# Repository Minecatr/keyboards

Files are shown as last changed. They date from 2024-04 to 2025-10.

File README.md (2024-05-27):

# Compiling firmware with QMK MSYS
- Install [QMK MSYS](https://msys.qmk.fm/)
- Setup QMK MSYS
- Clone this project into `qmk_firmware/keyboards/minecatr` *this means this repositories contents go in here
- Copy the build folder of the desired keyboard into the QMK MSYS directory
- Run `qmk compile -e CONVERT_TO=promicro_rp2040 -kb {PATH TO KEYBOARD} -km default` in QMK MSYS
- Output should be in `qmk_firmware/.build`
## Using other bootloaders
If your MCU does not use UF2 it likely supports one of these other bootloaders
### Caterina
`qmk flash -kb /build -km default`

### [Other Bootloaders](https://github.com/qmk/qmk_firmware/blob/master/docs/flashing.md)
# Using VIA to change layout
- Install [VIA](https://github.com/the-via/releases/releases) or use the [web version](https://www.usevia.app/)
- Navigate to settings and enable show design tab
- Navigate to design and press load
- Select the the via.json file of the desired board

a preconfigured layout.json is in each complete board

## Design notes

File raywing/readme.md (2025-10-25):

# RAYWING



a split choc keyboard with 54 backlit keys 2 rotary encoders and a flippable board
## Parts
- RGB LEDs: SK6812 MINI-E 100pcs https://www.aliexpress.us/item/2255800289371100.html
- MCU: Any Arduino Pro Micro Form Board
- EVQWGD001 Encoder: https://www.aliexpress.us/item/3256806010310254.html
- Diodes: DO-35 1N4148 100pcs https://www.aliexpress.us/item/3256805608834808.html
- Hotswap: Mill-Max Sockets (any) https://ringerkeys.com/collections/modders-tools/products/mill-max-hot-swap-sockets?variant=32793029312594](https://mech.land/products/mill-max-sockets?variant=39832065081497
- Switches: Any Choc V1 Compatible https://chosfox.com/collections/kailh-low-profile-switch-pg1350/products/kailh-chocs
- Keycaps: Any Choc V1 Compatible
- TRRS: PJ-320A https://www.aliexpress.us/item/2251832843150354.html
- TRRS Cable: Any 4 Ring TRRS Cable
  - If you have a 3 ring cut off the last pin on the TRRS socket
## Ordering A PCB
1. Download Gerbers Located `/kicad/production/Raywing.zip`
2. Choose Preferred PCB service
  - JLCPCB: https://cart.jlcpcb.com/quote
  - PCBWAY: https://www.pcbway.com/
  - DIGIKEY: https://www.digikey.com/en/resources/design-tools/pcb-build
3. Upload Gerbers
4. Order PCB

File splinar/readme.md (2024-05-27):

# Splinar

SPLINAR
a split choc keyboard with 54 keys and a flippable pcb

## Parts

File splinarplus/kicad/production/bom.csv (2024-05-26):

Designator | Footprint | Quantity | Value | LCSC Part #
D1, D10, D11, D12, D13, D14, D15, D16, D17, D18, D19, D2, D20, D21, D22, D23, D24, D25, D26, D27, D28, D3, D4, D5, D6, D7, D8, D9 | Diode_DO-35-FLIP | 28 | Diode
D29, D30, D31, D32, D33, D34, D35, D36, D37, D38, D39, D40, D41, D42, D43, D44, D45, D46, D47, D48, D49, D50, D51, D52, D53, D54, D55 | SK6812_mini_e_flipable | 27 | LED_SK6812MINI
S1, S10, S11, S12, S13, S14, S15, S16, S17, S18, S19, S2, S20, S21, S22, S23, S24, S25, S26, S27, S3, S4, S5, S6, S7, S8, S9 | Kailh-PG1350-1u-reversible-No-Clickhole | 27 | Keyswitch
SW1 | SW_PUSH_6mm_H4.3mm | 1 | SW_Push
SW2 | evqwgd001 | 1 | RotaryEncoder_Switch
U1 | TRRS_PJ-320A_FLIP | 1 | TRRS
U2 | Nice_Nano_V2 | 1 | Nice_Nano_V2

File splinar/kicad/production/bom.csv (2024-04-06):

Designator | Footprint | Quantity | Value | LCSC Part #
D1, D10, D11, D12, D13, D14, D15, D16, D17, D18, D19, D2, D20, D21, D22, D23, D24, D25, D26, D27, D28, D3, D4, D5, D6, D7, D8, D9 | Diode_DO-35-FLIP | 28 | Diode
S1, S10, S11, S12, S13, S14, S15, S16, S17, S18, S19, S2, S20, S21, S22, S23, S24, S25, S26, S27, S28, S3, S4, S5, S6, S7, S8, S9 | Kailh-PG1350-1u-reversible-No-Clickhole | 28 | Keyswitch
SW1 | SW_Tactile_SPST_Angled_MJTP1117 | 1 | SW_Push
U1 | TRRS_PJ-320A_FLIP | 1 | TRRS
U2 | Nice_Nano_V2 | 1 | Nice_Nano_V2

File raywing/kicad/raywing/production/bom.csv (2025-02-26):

Designator | Footprint | Quantity | Value | LCSC Part #
D1, D10, D11, D12, D13, D14, D15, D16, D17, D18, D19, D2, D20, D21, D22, D3, D4, D5, D6, D7, D8, D9 | Diode_DO-35-FLIP | 22 | Diode
D23, D24, D25, D26, D27, D28, D29, D30, D31, D32, D33, D34, D35, D36, D37, D38, D39, D40, D41, D42, D43 | SK6812_mini_e_flipable | 21 | LED_SK6812MINI
J1 | OLED_128x32 | 1 | OLED_128x32
S1, S10, S11, S12, S13, S14, S15, S16, S17, S18, S19, S2, S20, S21, S3, S4, S5, S6, S7, S8, S9 | Hotswap_Choc_FLIP | 21 | Keyswitch
SW1 | evqwgd001 | 1 | RotaryEncoder_Switch
SW2 | SW_SPST_TL3342_FLIP | 1 | SW_Push
U1 | TRRS_PJ-320A_FLIP | 1 | TRRS
U2 | Nice_Nano_V2 | 1 | Nice_Nano_V2

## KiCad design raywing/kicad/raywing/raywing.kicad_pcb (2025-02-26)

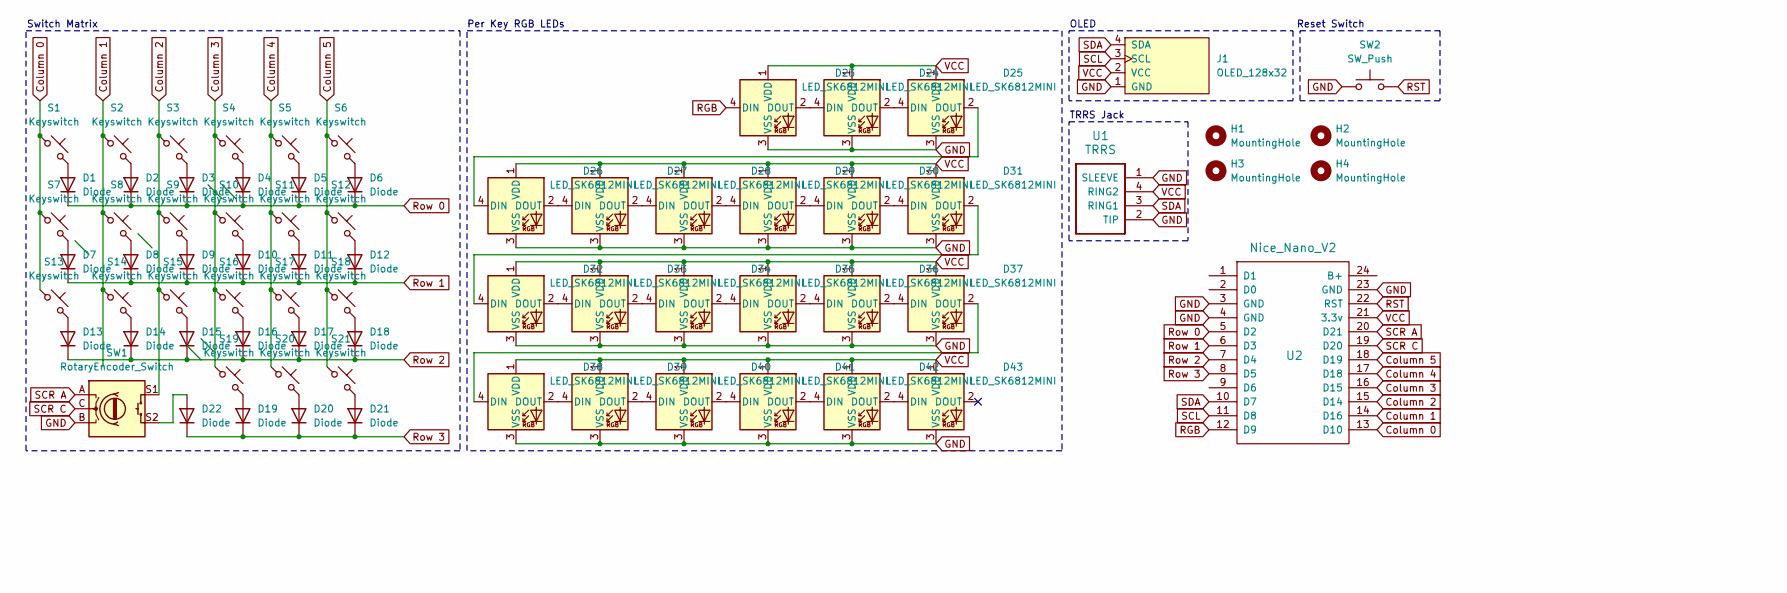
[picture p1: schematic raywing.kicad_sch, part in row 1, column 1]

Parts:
D1, D2, D3, D4, D5, D6, D7, D8, D9, D10, D11, D12, D13, D14, D15, D16, D17, D18, D19, D20, D21, D22: Diode; Diode_DO-35-FLIP
D23, D24, D25, D26, D27, D28, D29, D30, D31, D32, D33, D34, D35, D36, D37, D38, D39, D40, D41, D42, D43: LED_SK6812MINI; SK6812_mini_e_flipable
H1, H2, H3, H4: MountingHole; MountingHole_2.2mm_M2_Pad_Via
J1: OLED_128x32
S1, S2, S3, S4, S5, S6, S7, S8, S9, S10, S11, S12, S13, S14, S15, S16, S17, S18, S19, S20, S21: Keyswitch; Hotswap_Choc_FLIP
SW1: RotaryEncoder_Switch; evqwgd001
SW2: SW_Push; SW_SPST_TL3342_FLIP
U1: TRRS; TRRS_PJ-320A_FLIP
U2: Nice_Nano_V2

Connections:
Column 0: S1.1, S7.1, S13.1, U2.13 (D10)
Column 1: S2.1, S8.1, S14.1, U2.14 (D16)
Column 2: S3.1, S9.1, S15.1, SW1.S1, U2.15 (D14)
Column 3: S4.1, S10.1, S16.1, S19.1, U2.16 (D15)
Column 4: S5.1, S11.1, S17.1, S20.1, U2.17 (D18)
Column 5: S6.1, S12.1, S18.1, S21.1, U2.18 (D19)
GND: D23.3 (VSS), D24.3 (VSS), D25.3 (VSS), D26.3 (VSS), D27.3 (VSS), D28.3 (VSS), D29.3 (VSS), D30.3 (VSS), D31.3 (VSS), D32.3 (VSS), D33.3 (VSS), D34.3 (VSS), D35.3 (VSS), D36.3 (VSS), D37.3 (VSS), D38.3 (VSS), D39.3 (VSS), D40.3 (VSS), D41.3 (VSS), D42.3 (VSS), D43.3 (VSS), J1.1 (GND), SW1.B, SW2.1, U1.1 (SLEEVE), U1.2 (TIP), U2.3 (GND), U2.4 (GND), U2.23 (GND)
unnamed: D1.2 (A), S1.2
unnamed: D2.2 (A), S2.2
unnamed: D3.2 (A), S3.2
unnamed: D4.2 (A), S4.2
unnamed: D5.2 (A), S5.2
unnamed: D6.2 (A), S6.2
unnamed: D7.2 (A), S7.2
unnamed: D8.2 (A), S8.2
unnamed: D9.2 (A), S9.2
unnamed: D10.2 (A), S10.2
unnamed: D11.2 (A), S11.2
unnamed: D12.2 (A), S12.2
unnamed: D13.2 (A), S13.2
unnamed: D14.2 (A), S14.2
unnamed: D15.2 (A), S15.2
unnamed: D16.2 (A), S16.2
unnamed: D17.2 (A), S17.2
unnamed: D18.2 (A), S18.2
unnamed: D19.2 (A), S19.2
unnamed: D20.2 (A), S20.2
unnamed: D21.2 (A), S21.2
unnamed: D22.2 (A), SW1.S2
unnamed: D23.2 (DOUT), D24.4 (DIN)
unnamed: D24.2 (DOUT), D25.4 (DIN)
unnamed: D25.2 (DOUT), D26.4 (DIN)
unnamed: D26.2 (DOUT), D27.4 (DIN)
unnamed: D27.2 (DOUT), D28.4 (DIN)
unnamed: D28.2 (DOUT), D29.4 (DIN)
unnamed: D29.2 (DOUT), D30.4 (DIN)
unnamed: D30.2 (DOUT), D31.4 (DIN)
unnamed: D31.2 (DOUT), D32.4 (DIN)
unnamed: D32.2 (DOUT), D33.4 (DIN)
unnamed: D33.2 (DOUT), D34.4 (DIN)
unnamed: D34.2 (DOUT), D35.4 (DIN)
unnamed: D35.2 (DOUT), D36.4 (DIN)
unnamed: D36.2 (DOUT), D37.4 (DIN)
unnamed: D37.2 (DOUT), D38.4 (DIN)
unnamed: D38.2 (DOUT), D39.4 (DIN)
unnamed: D39.2 (DOUT), D40.4 (DIN)
unnamed: D40.2 (DOUT), D41.4 (DIN)
unnamed: D41.2 (DOUT), D42.4 (DIN)
unnamed: D42.2 (DOUT), D43.4 (DIN)
RGB: D23.4 (DIN), U2.12 (D9)
RST: SW2.2, U2.22 (RST)
Row 0: D1.1 (K), D2.1 (K), D3.1 (K), D4.1 (K), D5.1 (K), D6.1 (K), U2.5 (D2)
Row 1: D7.1 (K), D8.1 (K), D9.1 (K), D10.1 (K), D11.1 (K), D12.1 (K), U2.6 (D3)
Row 2: D13.1 (K), D14.1 (K), D15.1 (K), D16.1 (K), D17.1 (K), D18.1 (K), U2.7 (D4)
Row 3: D19.1 (K), D20.1 (K), D21.1 (K), D22.1 (K), U2.8 (D5)
SCL: J1.3 (SCL), U2.11 (D8)
SCR A: SW1.A, U2.20 (D21)
SCR C: SW1.C, U2.19 (D20)
SDA: J1.4 (SDA), U1.3 (RING1), U2.10 (D7)
VCC: D23.1 (VDD), D24.1 (VDD), D25.1 (VDD), D26.1 (VDD), D27.1 (VDD), D28.1 (VDD), D29.1 (VDD), D30.1 (VDD), D31.1 (VDD), D32.1 (VDD), D33.1 (VDD), D34.1 (VDD), D35.1 (VDD), D36.1 (VDD), D37.1 (VDD), D38.1 (VDD), D39.1 (VDD), D40.1 (VDD), D41.1 (VDD), D42.1 (VDD), D43.1 (VDD), J1.2 (VCC), U1.4 (RING2), U2.21 (3.3v)

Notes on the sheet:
Switch Matrix
Reset Switch
OLED
TRRS Jack
Per Key RGB LEDs

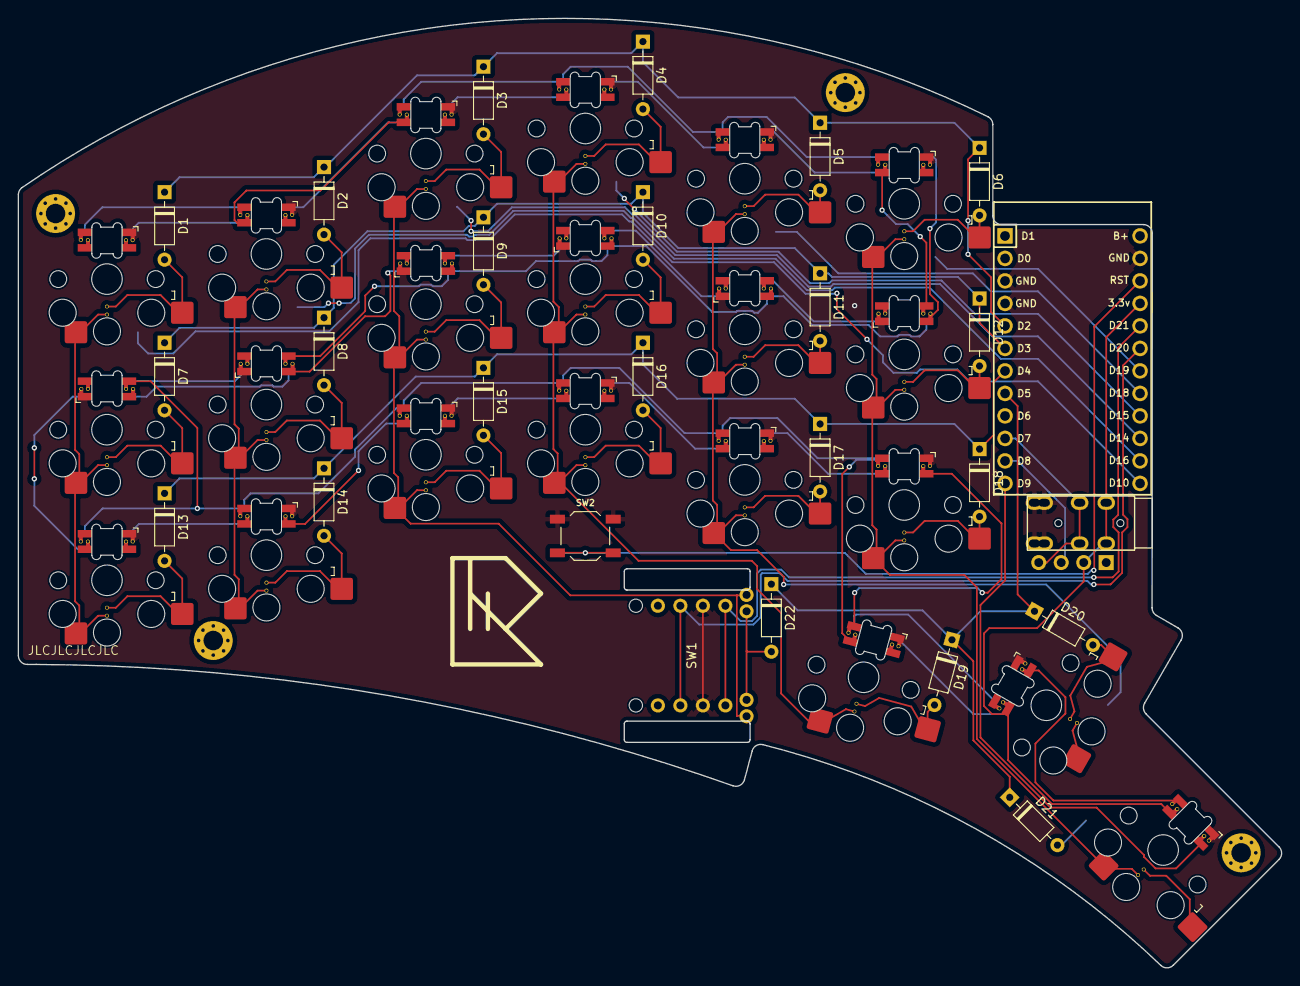
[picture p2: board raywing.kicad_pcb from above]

Board: 2 copper layers, 142.6 x 107.2 mm, 73 parts (0 on the bottom side), 60 nets.

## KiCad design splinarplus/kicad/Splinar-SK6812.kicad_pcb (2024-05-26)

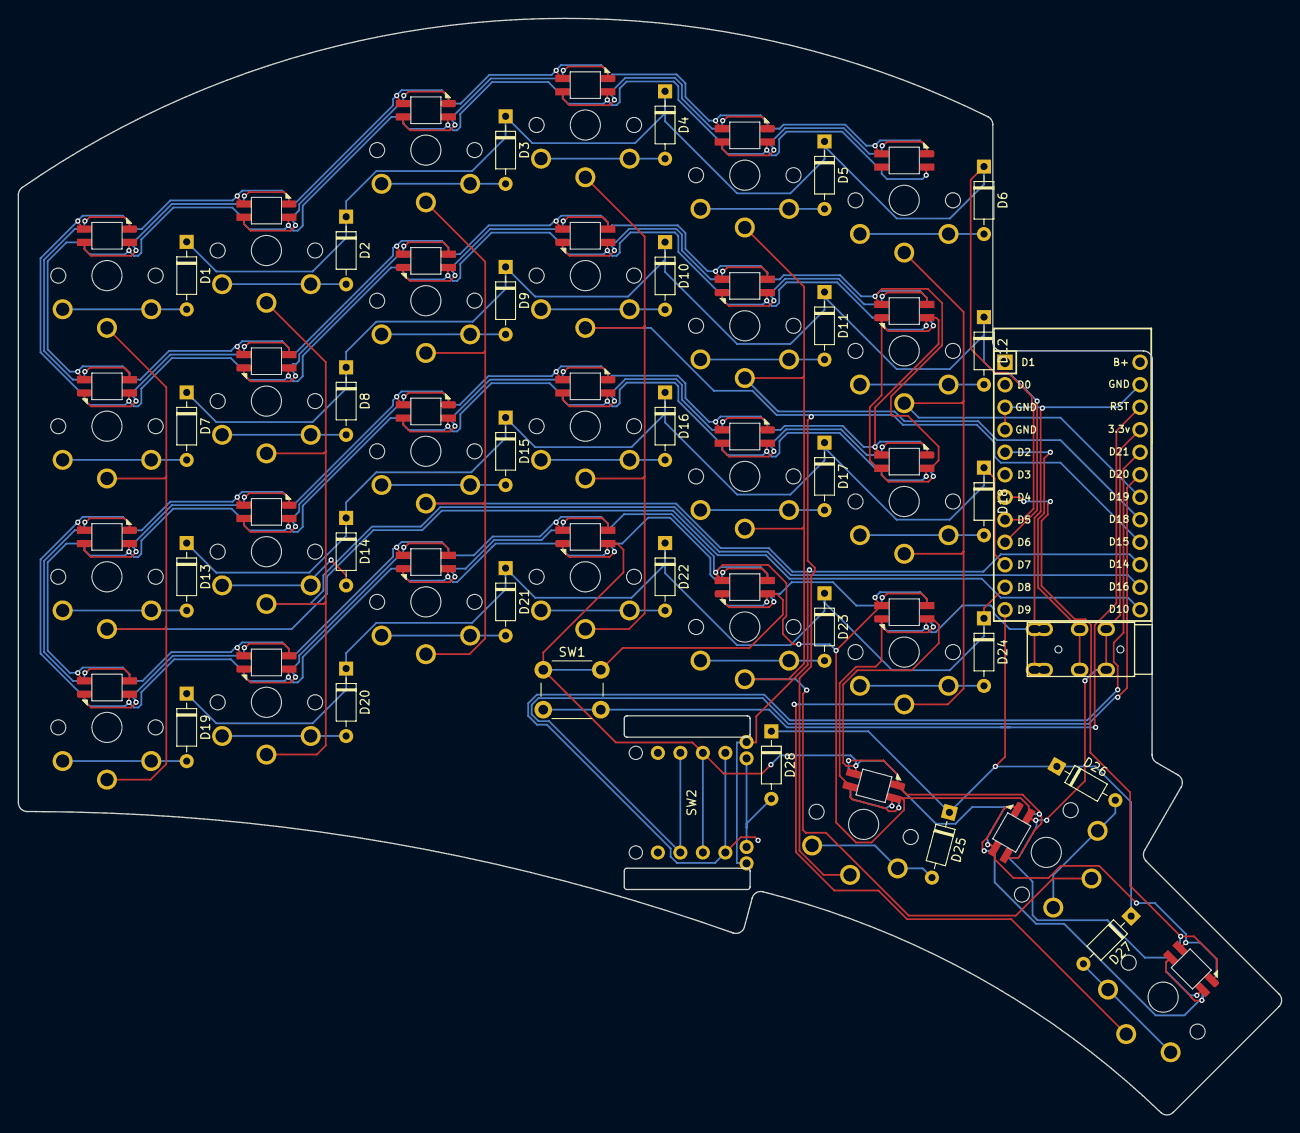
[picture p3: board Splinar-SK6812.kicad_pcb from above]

Board: 2 copper layers, 142.6 x 123.8 mm, 86 parts (0 on the bottom side), 72 nets.

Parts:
D1, D2, D3, D4, D5, D6, D7, D8, D9, D10, D11, D12, D13, D14, D15, D16, D17, D18, D19, D20, D21, D22, D23, D24, D25, D26, D27, D28: Diode; Diode_DO-35-FLIP
D29, D30, D31, D32, D33, D34, D35, D36, D37, D38, D39, D40, D41, D42, D43, D44, D45, D46, D47, D48, D49, D50, D51, D52, D53, D54, D55: LED_SK6812MINI
S1, S2, S3, S4, S5, S6, S7, S8, S9, S10, S11, S12, S13, S14, S15, S16, S17, S18, S19, S20, S21, S22, S23, S24, S25, S26, S27: Keyswitch; Kailh-PG1350-1u-reversible-No-Clickhole
SW1: SW_Push; SW_PUSH_6mm_H4.3mm
SW2: RotaryEncoder_Switch; evqwgd001
U1: TRRS; TRRS_PJ-320A_FLIP
U2: Nice_Nano_V2

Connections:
Column 0: S1.1, S7.1, S13.1, S19.1, U2.13 (D10)
Column 1: S2.1, S8.1, S14.1, S20.1, U2.14 (D16)
Column 2: S3.1, S9.1, S15.1, S21.1, SW2.S1, U2.15 (D14)
Column 3: S4.1, S10.1, S16.1, S22.1, S25.1, U2.16 (D15)
Column 4: S5.1, S11.1, S17.1, S23.1, S26.1, U2.17 (D18)
Column 5: S6.1, S12.1, S18.1, S24.1, S27.1, U2.18 (D19)
GND: D29.2 (VSS), D30.2 (VSS), D31.2 (VSS), D32.2 (VSS), D33.2 (VSS), D34.2 (VSS), D35.2 (VSS), D36.2 (VSS), D37.2 (VSS), D38.2 (VSS), D39.2 (VSS), D40.2 (VSS), D41.2 (VSS), D42.2 (VSS), D43.2 (VSS), D44.2 (VSS), D45.2 (VSS), D46.2 (VSS), D47.2 (VSS), D48.2 (VSS), D49.2 (VSS), D50.2 (VSS), D51.2 (VSS), D52.2 (VSS), D53.2 (VSS), D54.2 (VSS), D55.2 (VSS), SW1.1, SW2.B, U1.1 (SLEEVE), U1.2 (TIP), U2.3 (GND), U2.4 (GND), U2.23 (GND)
unnamed: D1.2 (A), S1.2
unnamed: D2.2 (A), S2.2
unnamed: D3.2 (A), S3.2
unnamed: D4.2 (A), S4.2
unnamed: D5.2 (A), S5.2
unnamed: D6.2 (A), S6.2
unnamed: D7.2 (A), S7.2
unnamed: D8.2 (A), S8.2
unnamed: D9.2 (A), S9.2
unnamed: D10.2 (A), S10.2
unnamed: D11.2 (A), S11.2
unnamed: D12.2 (A), S12.2
unnamed: D13.2 (A), S13.2
unnamed: D14.2 (A), S14.2
unnamed: D15.2 (A), S15.2
unnamed: D16.2 (A), S16.2
unnamed: D17.2 (A), S17.2
unnamed: D18.2 (A), S18.2
unnamed: D19.2 (A), S19.2
unnamed: D20.2 (A), S20.2
unnamed: D21.2 (A), S21.2
unnamed: D22.2 (A), S22.2
unnamed: D23.2 (A), S23.2
unnamed: D24.2 (A), S24.2
unnamed: D25.2 (A), S25.2
unnamed: D26.2 (A), S26.2
unnamed: D27.2 (A), S27.2
unnamed: D28.2 (A), SW2.S2
unnamed: D29.3 (DIN), D55.1 (DOUT)
unnamed: D30.1 (DOUT), D31.3 (DIN)
unnamed: D31.1 (DOUT), D32.3 (DIN)
unnamed: D32.1 (DOUT), D33.3 (DIN)
unnamed: D33.1 (DOUT), D34.3 (DIN)
unnamed: D34.1 (DOUT), D35.3 (DIN)
unnamed: D35.1 (DOUT), D36.3 (DIN)
unnamed: D36.1 (DOUT), D37.3 (DIN)
unnamed: D37.1 (DOUT), D38.3 (DIN)
unnamed: D38.1 (DOUT), D39.3 (DIN)
unnamed: D39.1 (DOUT), D40.3 (DIN)
unnamed: D40.1 (DOUT), D41.3 (DIN)
unnamed: D41.1 (DOUT), D42.3 (DIN)
unnamed: D42.1 (DOUT), D43.3 (DIN)
unnamed: D43.1 (DOUT), D44.3 (DIN)
unnamed: D44.1 (DOUT), D45.3 (DIN)
unnamed: D45.1 (DOUT), D46.3 (DIN)
unnamed: D46.1 (DOUT), D47.3 (DIN)
unnamed: D47.1 (DOUT), D48.3 (DIN)
unnamed: D48.1 (DOUT), D49.3 (DIN)
unnamed: D49.1 (DOUT), D50.3 (DIN)
unnamed: D50.1 (DOUT), D51.3 (DIN)
unnamed: D51.1 (DOUT), D52.3 (DIN)
unnamed: D52.1 (DOUT), D53.3 (DIN)
unnamed: D53.1 (DOUT), D54.3 (DIN)
unnamed: D54.1 (DOUT), D55.3 (DIN)
RGB: D30.3 (DIN), U2.7 (D4)
RST: SW1.2, U2.22 (RST)
Row 0: D1.1 (K), D2.1 (K), D3.1 (K), D4.1 (K), D5.1 (K), D6.1 (K), U2.8 (D5)
Row 1: D7.1 (K), D8.1 (K), D9.1 (K), D10.1 (K), D11.1 (K), D12.1 (K), U2.9 (D6)
Row 2: D13.1 (K), D14.1 (K), D15.1 (K), D16.1 (K), D17.1 (K), D18.1 (K), U2.10 (D7)
Row 3: D19.1 (K), D20.1 (K), D21.1 (K), D22.1 (K), D23.1 (K), D24.1 (K), U2.11 (D8)
Row 4: D25.1 (K), D26.1 (K), D27.1 (K), D28.1 (K), U2.12 (D9)
SCR A: SW2.A, U2.20 (D21)
SCR C: SW2.C, U2.19 (D20)
SDA: U1.3 (RING1), U2.5 (D2)
VCC: D29.4 (VDD), D30.4 (VDD), D31.4 (VDD), D32.4 (VDD), D33.4 (VDD), D34.4 (VDD), D35.4 (VDD), D36.4 (VDD), D37.4 (VDD), D38.4 (VDD), D39.4 (VDD), D40.4 (VDD), D41.4 (VDD), D42.4 (VDD), D43.4 (VDD), D44.4 (VDD), D45.4 (VDD), D46.4 (VDD), D47.4 (VDD), D48.4 (VDD), D49.4 (VDD), D50.4 (VDD), D51.4 (VDD), D52.4 (VDD), D53.4 (VDD), D54.4 (VDD), D55.4 (VDD), U1.4 (RING2), U2.21 (3.3v)

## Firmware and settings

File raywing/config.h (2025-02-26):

/*
This is the c configuration file for the keymap

Copyright 2012 Jun Wako <wakojun@gmail.com>
Copyright 2015 Jack Humbert

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
You should have received a copy of the GNU General Public License
along with this program.  If not, see <http://www.gnu.org/licenses/>.
*/

#pragma once

/* Select hand configuration */

#define MASTER_LEFT
// #define MASTER_RIGHT
// #define EE_HANDS
#define DYNAMIC_KEYMAP_LAYER_COUNT 5

#define ENCODERS_PAD_A { F4 }
#define ENCODERS_PAD_B { F5 }

#define ENCODERS_PAD_A_RIGHT { F4 }
#define ENCODERS_PAD_B_RIGHT { F5 }

#define ENCODER_RESOLUTION 2
#define MOUSEKEY_MOVE_DELTA 1
// #define OLED_DISPLAY_128x32

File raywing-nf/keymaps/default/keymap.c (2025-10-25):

#include QMK_KEYBOARD_H


#ifdef ENCODER_MAP_ENABLE
const uint16_t PROGMEM encoder_map[][NUM_ENCODERS][NUM_DIRECTIONS] = {
    [0] = { ENCODER_CCW_CW(_______, _______), ENCODER_CCW_CW(KC_VOLD, KC_VOLU)  },
    [1] = { ENCODER_CCW_CW(_______, _______), ENCODER_CCW_CW(KC_VOLD, KC_VOLU)  },
    [2] = { ENCODER_CCW_CW(_______, _______), ENCODER_CCW_CW(_______, _______)  },
    [3] = { ENCODER_CCW_CW(_______, _______), ENCODER_CCW_CW(_______, _______)  },
    [4] = { ENCODER_CCW_CW(_______, _______), ENCODER_CCW_CW(_______, _______) }
};
#endif

const uint16_t PROGMEM keymaps[][MATRIX_ROWS][MATRIX_COLS] = {


  [0] = LAYOUT(
  //┌────────┬────────┬────────┬────────┬────────┬────────┐                                   ┌────────┬────────┬────────┬────────┬────────┬────────┐
     KC_ESC,  KC_Q,    KC_W,    KC_F,    KC_P,    KC_B,                                        KC_J,    KC_L,    KC_U,    KC_Y,    KC_QUOT, KC_DEL,
  //├────────┼────────┼────────┼────────┼────────┼────────┤                                   ├────────┼────────┼────────┼────────┼────────┼────────┤
     KC_LSFT, KC_A,    KC_R,    KC_S,    KC_T,    KC_G,                                        KC_M,    KC_N,    KC_E,    KC_I,    KC_O,    KC_RSFT,
  //├────────┼────────┼────────┼────────┼────────┼────────┤                                   ├────────┼────────┼────────┼────────┼────────┼────────┤
     KC_LCTL, KC_Z,    KC_X,    KC_C,    KC_D,    KC_V,                                        KC_K,    KC_H,    KC_COMM, KC_DOT,  KC_SLSH, KC_SCLN,
  //└────────┴────────┴────────┴───┬────┴───┬────┴───┬────┴───┬────────┐        ┌────────┬────┴───┬────┴───┬────┴───┬────┴────────┴────────┴────────┘
                                    KC_LGUI, KC_LALT, KC_SPC,  MO(2),            MO(3),   KC_BSPC, KC_ENT,  KC_RALT
  //                               └────────┴────────┴────────┴────────┘        └────────┴────────┴────────┴────────┘
  ),

  [1] = LAYOUT(
  //┌────────┬────────┬────────┬────────┬────────┬────────┐                                   ┌────────┬────────┬────────┬────────┬────────┬────────┐
     KC_T,    KC_ESC,  KC_Q,    KC_W,    KC_E,    KC_R,                                        KC_Y,    KC_U,    KC_I,    KC_O,    KC_QUOT,  KC_DEL,
  //├────────┼────────┼────────┼────────┼────────┼────────┤                                   ├────────┼────────┼────────┼────────┼────────┼────────┤
     KC_G,    KC_LSFT, KC_A,    KC_S,    KC_D,    KC_F,                                        KC_H,    KC_J,    KC_K,    KC_L,    KC_SCLN, KC_RSFT,
  //├────────┼────────┼────────┼────────┼────────┼────────┤                                   ├────────┼────────┼────────┼────────┼────────┼────────┤
     KC_B,    KC_LCTL, KC_Z,    KC_X,    KC_C,    KC_V,                                        KC_N,    KC_M,    KC_COMM, KC_DOT,  KC_SLSH, KC_P,
  //└────────┴────────┴────────┴───┬────┴───┬────┴───┬────┴───┬────────┐        ┌────────┬────┴───┬────┴───┬────┴───┬────┴────────┴────────┴────────┘
                                    KC_LGUI, KC_LALT, KC_SPC,  MO(2),            MO(3),   KC_BSPC, KC_ENT,  KC_RALT
  //                               └────────┴────────┴────────┴────────┘        └────────┴────────┴────────┴────────┘
  ),

  [2] = LAYOUT(
  //┌────────┬────────┬────────┬────────┬────────┬────────┐                                   ┌────────┬────────┬────────┬────────┬────────┬────────┐
     TG(1),   KC_SLSH, KC_7,    KC_8,    KC_9,    KC_MINS,                                     S(KC_7), S(KC_8), KC_LBRC,S(KC_LBRC),KC_GRV, KC_INS,
  //├────────┼────────┼────────┼────────┼────────┼────────┤                                   ├────────┼────────┼────────┼────────┼────────┼────────┤
     _______, S(KC_8), KC_4,    KC_5,    KC_6,    KC_EQL,                                      S(KC_6), S(KC_0), KC_RBRC,S(KC_RBRC),S(KC_1),_______,
  //├────────┼────────┼────────┼────────┼────────┼────────┤                                   ├────────┼────────┼────────┼────────┼────────┼────────┤
     _______, KC_0,    KC_1,    KC_2,    KC_3,    KC_TAB,                                      S(KC_5), S(KC_2), S(KC_3), S(KC_4), KC_BSLS, KC_RCTL,
  //└────────┴────────┴────────┴───┬────┴───┬────┴───┬────┴───┬────────┐        ┌────────┬────┴───┬────┴───┬────┴───┬────┴────────┴────────┴────────┘
                                    _______, _______, _______, _______,          MO(4),   _______, _______, _______
  //                               └────────┴────────┴────────┴────────┘        └────────┴────────┴────────┴────────┘
  ),

  [3] = LAYOUT(
  //┌────────┬────────┬────────┬────────┬────────┬────────┐                                   ┌────────┬────────┬────────┬────────┬────────┬────────┐
     _______, KC_F12,  KC_F7,   KC_F8,   KC_F9,   _______,                                     KC_VOLU, KC_PGDN, KC_UP,   KC_PGUP, KC_HOME, _______,
  //├────────┼────────┼────────┼────────┼────────┼────────┤                                   ├────────┼────────┼────────┼────────┼────────┼────────┤
     _______, KC_F11,  KC_F4,   KC_F5,   KC_F6,   _______,                                     _______, KC_LEFT, KC_DOWN, KC_RGHT, KC_END,  _______,
  //├────────┼────────┼────────┼────────┼────────┼────────┤                                   ├────────┼────────┼────────┼────────┼────────┼────────┤
     _______, KC_F10,  KC_F1,   KC_F2,   KC_F3,   _______,                                     KC_VOLD, KC_MPRV, KC_MPLY, KC_MNXT, _______, _______,
  //└────────┴────────┴────────┴───┬────┴───┬────┴───┬────┴───┬────────┐        ┌────────┬────┴───┬────┴───┬────┴───┬────┴────────┴────────┴────────┘
                                    _______, _______, _______, MO(4),            _______, _______, _______, _______
  //                               └────────┴────────┴────────┴────────┘        └────────┴────────┴────────┴────────┘
  ),
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

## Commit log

2024-04-06 change splinar2 to splinar+
    [Splinar.kicad_pcb, Splinar.kicad_sch, Splinar.stretch_bkup.kicad_pcb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]
2024-05-27 Add rgb matrix
    [Splinar.kicad_pcb]
2024-05-28 fix switch
2025-02-26 raywing finished
    [bom.csv, designators.csv, positions.csv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]

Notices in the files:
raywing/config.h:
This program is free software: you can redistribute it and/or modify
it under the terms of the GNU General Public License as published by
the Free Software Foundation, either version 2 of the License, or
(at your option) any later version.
